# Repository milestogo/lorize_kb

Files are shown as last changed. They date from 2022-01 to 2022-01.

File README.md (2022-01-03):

# Lorize: a family of low profile 60% ergonomic keyboards that aren't too weird.  

These should be familiar to users of a MS natural or Sculpt keyboard, but pull in elements from the boardrun, alice, and kinesis keyboards. 
Available in desktop and MNT reform versions.

The lorize.scad file is intended to be used with the openscad configurator. You can change the type of keyboard (desktop, laptop, mutants), and the layer. The output can be used for laser cutting plate and case files. The POS files are used as an easy way to export centroid information from kicad & import into SCAD, which is used to make the bottom layer cutouts. 

lorize3 folder is for a desktop version of the PCB. it can be split for tenting, or used unsplit. This PCB can be soldered using only through hole 
techniques (no stencil).

The PCB for the laptop version is located at github milestogo/reform,in the ergo1 branch. This was done as a remix of the original keyboard, so that the factory firmware will still work. The board was updated to be single sided to reduce cost/effort of assembly. There isn't quite enough room to fit on top to fit a pro micro, so it requires SMD work. 

#Todos.
Vertical spacing between switches is using 17mm spacing. This feels big if you use MBK or other low height keycaps.  
For ease of hand routing, the laptop PCB has some weird parts I built. The diodes could be changed & the board autorouted. 

The desktop version's RGB LEDs aren't well placed. Consider replacing with crenelated tabs to solder LED strip on the edge. . 

The laptop version doesn't have RGB LEDs,underglow would work well for the MNT case, or edge lit by the trackpad.

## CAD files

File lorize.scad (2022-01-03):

include <part-POS.scad>;

$fn=30;

angle=14; //Total opening angle
splita=angle/2; 
colstep=19; // horizontal center to center distance between switches
rowstep=18; // ibid, vertical
m3=3.1/2;//radius of m3 hole

/* [Hole Type:] */
// Pick layer to set hole type. 0 = debug, 1 = switchplate
layer = 0; // [0:caps_debug, 1:switchplate, 2:pcb_frame, 3:pcb_shim, 4:palm_mid, 5: palm_rest] 

caps_debug=0;
switchplate=1;
pcb_frame=2;
palm_mid=4; 
palm_rest=5;

/* [ Enum of board types ] */
desktop = 0; //60% best overall ergos, custom PCB shape. 
maxreform = 1; // option with as many keys as we can cram in. 
reform = 2; // 60% that fits well enough for a reform sized PCB
smallreform_thumb =3 ;// 30% option with more thumbs for reform.  
long=1; // used to flag if switch has long or standard cap. 


/* [ Board Type:] */
board = 0; // [ 1:maxreform, 2:reform, 0:desktop, 3:smallreform_thumb]



/* [ PCB Size]*/
reform_pcbx = 275.9;
reform_pcby = 102.24;




// mcu board size
mcu_x= 34; // pro micro 33, feather 51
mcu_y= 19.5; // pro micro 19 /bluepill 22.6 / feather 23
mcu_z=8;





module rtate(x,y, a) {

	newx= x*cos(a) - y*sin(a);
	newy= x*sin(a) + y*cos(a);
}

//// Functions

/// x_origin,y_origin, angle of orgin from horizontal, x increment ,y increment, additional angle of column, separation between hands, do_longkey, per_key_rotation
module debugkey(x_o,y_o,a_o,x,y,a_col, separation,long,a_key,is_mirror) {

// even if we are mirroring motions, don't want to mirror parts. So mirror them again. 

	translate([separation,0,0]) {
		rotate(a_o)
			translate([x_o,y_o,0])
				rotate(a_col)
				translate([x,y,0])
					
						if(long) {
							if(a_key) {
								rotate(a_key) 
									if(is_mirror) {
										mirror([1,0,0])
											dolongkey();
									} else {
										dolongkey();
									}
							} else {
								if(is_mirror) {
										mirror([1,0,0])
											dolongkey();
									} else {
										dolongkey();
									}
							}
						} else {
							if(a_key) {
								rotate(a_key) 
									if(is_mirror) {
										mirror([1,0,0])
											dokey();
									} else {
										dokey();
									}
							} else {
								if(is_mirror) {
										mirror([1,0,0])
											dokey();
									} else {
										dokey();
									}
							}
						}

	}

	innerx=(x*cos(a_col) - y*sin(a_col));

	innery=(x*sin(a_col) + y*cos(a_col));

	outangle=a_key+a_col+a_o;
	out_x= separation + ( (x_o+innerx)*cos(a_o) - (y_o+innery)*sin(a_o))  ;
	out_y=  ( (x_o+innerx)*sin(a_o) + (y_o + innery) * cos(a_o))   ;

	if ( 0 == layer) { // debug caps 
		color ("blue")
			translate([out_x,out_y,0])
				rotate(outangle)
					circle(4/2);

	}
		echo ("Right at ",out_x +130 , 100-out_y, outangle) ;
		//echo ("Left at ",130-out_x , 100-out_y, outangle) ;
}	


module do_mcu_under(angle){

for (y=[-7.62,7.62]) {
	hull(){
		for(x=[-14,14])
			translate([x,y])
				circle(r=3.25/2);
		}
	}
}



module do_choc_under(){

	hull(){

		circle(r=3.7/2); // stem

		translate([-5.5,0,0]) // left peg
				circle(r=2/2);

		hull(){ // link connectors connector
			translate([-5,-3.75])
				circle(r=3.5/2);

			translate([0,-5.95])
				circle(r=3.5/2);

		}
			translate([-5,-3.75])
				square([4.8 ,5],center=true);

			translate([0,-5.95])
				square([4.4,5],center=true);

	}

		/*	pcb mount choc pin. Remove if not needed
			translate([5.5,0,0])
				circle(r=1.9/2);
		*/

		// choc mount
		translate([-8.275,-3.8]) // pad left
			square([2.8,2.8],center=true);
		translate([3.275,-5.95]) // pad right
			square([2.8,2.8],center=true);
	
}

module dokey(){
/* how big is a 1u choc cap?
generic black keycap set, x=17.6 y=16.65
PLUM keyboard 18x18
per key white 17.6x16.65
transparent 17.45 x 17.82
mbk 17,48 x 16.43
*/

	if ( 0 == layer) { // debug caps 
		difference(){
			square([17.75,17],center=true);
			circle(r=3);
		}
	} else if ( 1 == layer) { // switch plate
		square([14,14],center=true);

	} else { // PCB - replace with choc pcb footprint some day - useful for kicad conversion later?
		do_choc_under();
	}
}


module dolongkey(){
/* how big is a 1.5u?

generic nylon 26.6x16.6
generic white 26.7x16.65
generic black 26.55x16.5
mbk 26.6 x 16.5

*/
	if ( 0 == layer) {
		difference(){
			square([26.75,17],center=true);
			circle(r=3);
		}
	} else if ( 1 == layer) {
		square([14,14],center=true);

	} else { // PCB
		 do_choc_under();
	}
}



//  Punch out one half of the shape. 
module doright(	angles, vfudge,hfudge,rowlow,rowhi, separation, is_mirror ){	
			for (x=[1:5]) { // starting with middle finger towards pinky

				for(y=[rowlow[x]:rowhi[x]]) {
					debugkey (  (x-2)*colstep,0, splita,
								hfudge[x],vfudge[x]+(y)*rowstep, angles[x] ,separation, 0,0,is_mirror);
						
				}

				if (5==x) { // pinky shift key is special. 
					
					if (board == smallreform_thumb ) { // why can't the laptop have a big key too?
						debugkey ( 1+(x-2)* colstep, 0 , splita, 
								-0.5,  vfudge[x]+(-1)*rowstep , angles[x],separation,0,0,is_mirror);
					} else {
					
						debugkey ( (x-2+0.25)* colstep, 0 , splita, 
								-0.5,  vfudge[x]+(-1)*rowstep , angles[x],separation,1,0,is_mirror);
					}
				

				// pinky menu key	
						// small reform uses 1u keys, mostly for aesthetics. others use larger 1.5U
						if  (board != smallreform_thumb ) {
							debugkey ( (colstep*2.25), 0 , splita ,
								-0.75, -0.25+ vfudge[x] -2*rowstep, angles[x-1], separation, 1, 0,is_mirror);
						}
		
					// pinky ctrl key  
					if ( (board == maxreform) || board == desktop ) {				
						debugkey ( (3.5-.125)* colstep, 0 , splita, 
							2,   -1.5 - vfudge[x] -(2)*rowstep , angles[x], separation,0,0,is_mirror);
							}
				}

			
			}

			// x=0 index fingers have extra rotation to bring up spacebar y location. 
	 		for (x=0) {
				for(y=[rowlow[x]:rowhi[x]]) {
						debugkey ( (x-2)*colstep, 0 , splita ,
								hfudge[x], vfudge[x]+(y)*rowstep, angles[x], separation,0, -splita*0.55,is_mirror);
				}
			}


			// Far reach pinky keys 
			if ( (board == maxreform) || (board == reform)) {
								
				for (x=6) { // weird pinky keys

						if (board == maxreform || (board == reform) ) {
						for(y=[rowlow[x]]) {
							debugkey ( (x-2)*colstep, 0 , splita ,
								hfudge[x], vfudge[x]+(y-.5)*rowstep, angles[x], separation,0, 90,is_mirror);
						}

					}
				


				}
			}
}




module do_mcu(a){
//		[0,-4+66-mcu_y/2,0]	

// Pro micro
	color("blue")
		translate([0,-4+66-mcu_y/2,0]	) { // board+diameter
			rotate(a)
				hull()
					for(ix=[-1,1])
						for(iy=[-1,1])
							translate([ix*mcu_x/2,iy*mcu_y/2,0])
								circle(r=0.1);

				}
						


}





// desktop shape functions. 

module walkpoints(radius, start, count, nodes){
	for ( c=[start:count]) {
		translate(nodes[c])
			circle(r=radius);
	}
}


RightCorners=[ [0,0],
			[0,58],  // center top
					[62,64], //  outsidetop of mcu holder 192,36
					[72,48],// near u key // 205,49.5
					[112.5,49],// upper right
					[125,3], // bump on side
					[129,-35], //bottom right
					[27,-53], // side of spacebar
					[0,-53], // bottom center	
					[0,0],					
	];




/*raw, center at x=130,y=100
130,42
130,100
130, 153
200,49
60,49
254,98
6,98
148,135
112,135
*/

MountingHoles= [
[0,58],
[0,0],
[0,-53],
[70,51], [-70,51],
[-124,2], [124,2],
[18,-36],[-18,-35],
]
;


front=140;
gap=-20;
PalmrestMid =[  // middle ones, no gap added to allow access to keys
					[142,10-front],
					[129,-35], //bottom right
					[27,-53], // side of spacebar
					[0,-53], // bottom center
					[40,5-front],
					[00,5-front],
	];


PalmrestTop =[  // middle ones, no gap added to allow access to keys
					[142,10-front],
					[129,-35], //bottom right
					[40,-53], // side of spacebar
					[70,-53], // bottom center
					[50,5-front],
				
	];


LowerPalmrestCorners =[ 
					[145,10-front],
					[129,-35], //bottom right
					[27,-53], // side of spacebar
					[0,-53], // bottom center
					[50,-front],
					[0,-front],
			
	];


module hullpalms_mid() {  // upper palms
// no fancy angles, so we can do both sides. 
	difference() { 
			union() {
				hull()
					walkpoints(5, 0, 5, PalmrestMid);
		
				mirror([1,0,0])
					hull()
						walkpoints(5, 0, 5, PalmrestMid);
			
			}


		scale(1.01)
			hullaplate();

			// centering holes for palmrest. 
		for (x=[100,80,-80,-100]) 
			translate([x,-100,0])
				circle(r=3/2);

	}
}


	module hullpalms_top() {  // upper palms
// no fancy angles, so we can do both sides. 
	difference() { 
			union() {
				hull()
					walkpoints(5, 0, 4, PalmrestTop);
		
				*mirror([1,0,0])
					hull()
						walkpoints(5, 0, 5, PalmrestTop);
			
			}

		translate([0,-18,0])
		scale(1.05)
			hullaplate(0);


		translate([0,-150])
			rotate(45)
				square([150,150]);

			// centering holes for palmrest. 
		for (x=[100,80]) 
			translate([x,-100,0])
				circle(r=3/2);


	}
	
}
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

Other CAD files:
part-POS.scad

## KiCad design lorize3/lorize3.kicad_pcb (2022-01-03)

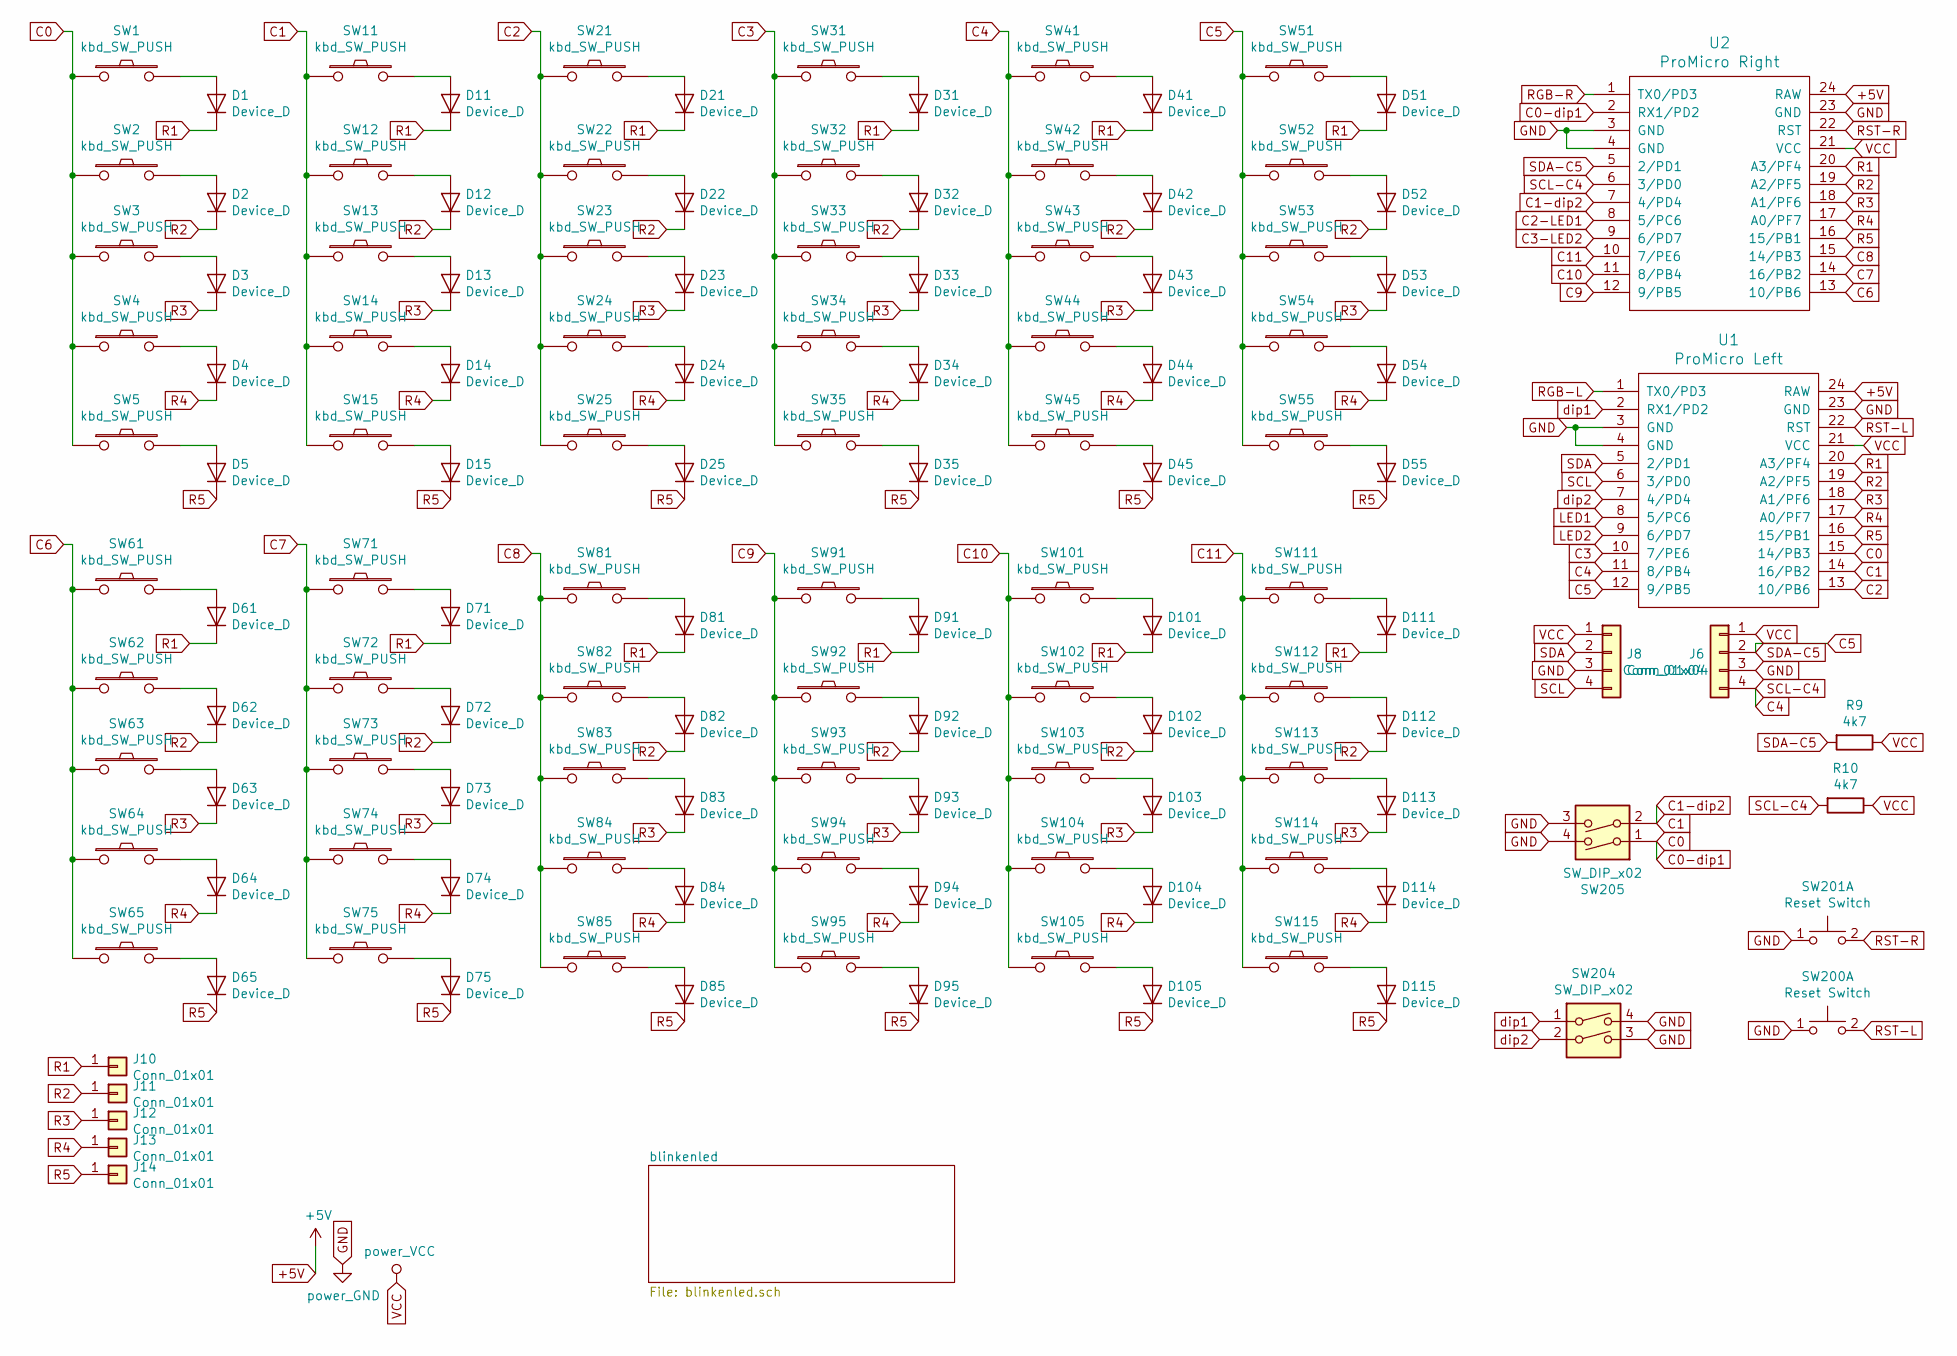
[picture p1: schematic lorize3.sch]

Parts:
D1, D2, D3, D4, D5, D11, D12, D13, D14, D15, D21, D22, D23, D24, D25, D31, D32, D33, D34, D35, D41, D42, D43, D44, D45, D51, D52, D53, D54, D55, D61, D62, D63, D64, D65, D71, D72, D73, D74, D75, D81, D82, D83, D84, D85, D91, D92, D93, D94, D95, D101, D102, D103, D104, D105, D111, D112, D113, D114, D115: Device_D; Diode-Hybrid-Back
J6, J8: Conn_01x04; 1X04_LONGPADS
J10, J11, J12, J13, J14: Conn_01x01; 1X01_LONGPAD
R9, R10: 4k7; Resistor-Hybrid-Back
SW1, SW2, SW3, SW4, SW5, SW11, SW12, SW13, SW14, SW15, SW21, SW22, SW23, SW24, SW25, SW31, SW32, SW33, SW34, SW35, SW41, SW42, SW43, SW44, SW45, SW51, SW52, SW53, SW54, SW55, SW61, SW62, SW63, SW64, SW65, SW71, SW72, SW73, SW74, SW75, SW81, SW82, SW83, SW84, SW85, SW91, SW92, SW93, SW94, SW95, SW101, SW102, SW103, SW104, SW105, SW111, SW112, SW113, SW114, SW115: kbd_SW_PUSH; Kailh_socket_PG1350
SW200, SW201: Reset Switch; SW_Tactile_SPST_Angled_MJTP1117
SW204, SW205: SW_DIP_x02; SW_DIP_SPSTx02_Slide_6.7x6.64mm_W7.62mm_P2.54mm_LowProfile
U1: ProMicro Left; ArduinoProMicro-notopsilk
U2: ProMicro Right; ArduinoProMicro-notopsilk

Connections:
+5V: U1.24 (RAW), U2.24 (RAW); also elsewhere on the board
C0: SW1.1, SW2.1, SW3.1, SW4.1, SW5.1, SW205.1, U1.15 (14/PB3), U2.2 (RX1/PD2)
C1: SW11.1, SW12.1, SW13.1, SW14.1, SW15.1, SW205.2, U1.14 (16/PB2), U2.7 (4/PD4)
C2: SW21.1, SW22.1, SW23.1, SW24.1, SW25.1, U1.13 (10/PB6), U2.8 (5/PC6); also elsewhere on the board
C3: SW31.1, SW32.1, SW33.1, SW34.1, SW35.1, U1.10 (7/PE6), U2.9 (6/PD7); also elsewhere on the board
C4: J6.4, R10.2, SW41.1, SW42.1, SW43.1, SW44.1, SW45.1, U1.11 (8/PB4), U2.6 (3/PD0)
C5: J6.2, R9.2, SW51.1, SW52.1, SW53.1, SW54.1, SW55.1, U1.12 (9/PB5), U2.5 (2/PD1)
C6: SW61.1, SW62.1, SW63.1, SW64.1, SW65.1, U2.13 (10/PB6)
C7: SW71.1, SW72.1, SW73.1, SW74.1, SW75.1, U2.14 (16/PB2)
C8: SW81.1, SW82.1, SW83.1, SW84.1, SW85.1, U2.15 (14/PB3)
C9: SW91.1, SW92.1, SW93.1, SW94.1, SW95.1, U2.12 (9/PB5)
C10: SW101.1, SW102.1, SW103.1, SW104.1, SW105.1, U2.11 (8/PB4)
C11: SW111.1, SW112.1, SW113.1, SW114.1, SW115.1, U2.10 (7/PE6)
GND: J6.3, J8.3, SW200.1, SW201.1, SW204.3, SW204.4, SW205.3, SW205.4, U1.3 (GND), U1.4 (GND), U1.23 (GND), U2.3 (GND), U2.4 (GND), U2.23 (GND); also elsewhere on the board
LED1: U1.8 (5/PC6); also elsewhere on the board
LED2: U1.9 (6/PD7); also elsewhere on the board
unnamed: D1.2 (A), SW1.2
unnamed: D2.2 (A), SW2.2
unnamed: D3.2 (A), SW3.2
unnamed: D4.2 (A), SW4.2
unnamed: D5.2 (A), SW5.2
unnamed: D11.2 (A), SW11.2
unnamed: D12.2 (A), SW12.2
unnamed: D13.2 (A), SW13.2
unnamed: D14.2 (A), SW14.2
unnamed: D15.2 (A), SW15.2
unnamed: D21.2 (A), SW21.2
unnamed: D22.2 (A), SW22.2
unnamed: D23.2 (A), SW23.2
unnamed: D24.2 (A), SW24.2
unnamed: D25.2 (A), SW25.2
unnamed: D31.2 (A), SW31.2
unnamed: D32.2 (A), SW32.2
unnamed: D33.2 (A), SW33.2
unnamed: D34.2 (A), SW34.2
unnamed: D35.2 (A), SW35.2
unnamed: D41.2 (A), SW41.2
unnamed: D42.2 (A), SW42.2
unnamed: D43.2 (A), SW43.2
unnamed: D44.2 (A), SW44.2
unnamed: D45.2 (A), SW45.2
unnamed: D51.2 (A), SW51.2
unnamed: D52.2 (A), SW52.2
unnamed: D53.2 (A), SW53.2
unnamed: D54.2 (A), SW54.2
unnamed: D55.2 (A), SW55.2
unnamed: D61.2 (A), SW61.2
unnamed: D62.2 (A), SW62.2
unnamed: D63.2 (A), SW63.2
unnamed: D64.2 (A), SW64.2
unnamed: D65.2 (A), SW65.2
unnamed: D71.2 (A), SW71.2
unnamed: D72.2 (A), SW72.2
unnamed: D73.2 (A), SW73.2
unnamed: D74.2 (A), SW74.2
unnamed: D75.2 (A), SW75.2
unnamed: D81.2 (A), SW81.2
unnamed: D82.2 (A), SW82.2
unnamed: D83.2 (A), SW83.2
unnamed: D84.2 (A), SW84.2
unnamed: D85.2 (A), SW85.2
unnamed: D91.2 (A), SW91.2
unnamed: D92.2 (A), SW92.2
unnamed: D93.2 (A), SW93.2
unnamed: D94.2 (A), SW94.2
unnamed: D95.2 (A), SW95.2
unnamed: D101.2 (A), SW101.2
unnamed: D102.2 (A), SW102.2
unnamed: D103.2 (A), SW103.2
unnamed: D104.2 (A), SW104.2
unnamed: D105.2 (A), SW105.2
unnamed: D111.2 (A), SW111.2
unnamed: D112.2 (A), SW112.2
unnamed: D113.2 (A), SW113.2
unnamed: D114.2 (A), SW114.2
unnamed: D115.2 (A), SW115.2
R1: D1.1 (K), D11.1 (K), D21.1 (K), D31.1 (K), D41.1 (K), D51.1 (K), D61.1 (K), D71.1 (K), D81.1 (K), D91.1 (K), D101.1 (K), D111.1 (K), J10.1, U1.20 (A3/PF4), U2.20 (A3/PF4); also elsewhere on the board
R5: D5.1 (K), D15.1 (K), D25.1 (K), D35.1 (K), D45.1 (K), D55.1 (K), D65.1 (K), D75.1 (K), D85.1 (K), D95.1 (K), D105.1 (K), D115.1 (K), J14.1, U1.16 (15/PB1), U2.16 (15/PB1); also elsewhere on the board
RGB-L: U1.1 (TX0/PD3); also elsewhere on the board
RGB-R: U2.1 (TX0/PD3); also elsewhere on the board
RST-L: SW200.2, U1.22 (RST)
RST-R: SW201.2, U2.22 (RST)
SCL: J8.4, U1.6 (3/PD0)
SDA: J8.2, U1.5 (2/PD1)
VCC: J6.1, J8.1, R9.1, R10.1, U1.21 (VCC), U2.21 (VCC); also elsewhere on the board
dip1: SW204.1, U1.2 (RX1/PD2)
dip2: SW204.2, U1.7 (4/PD4)

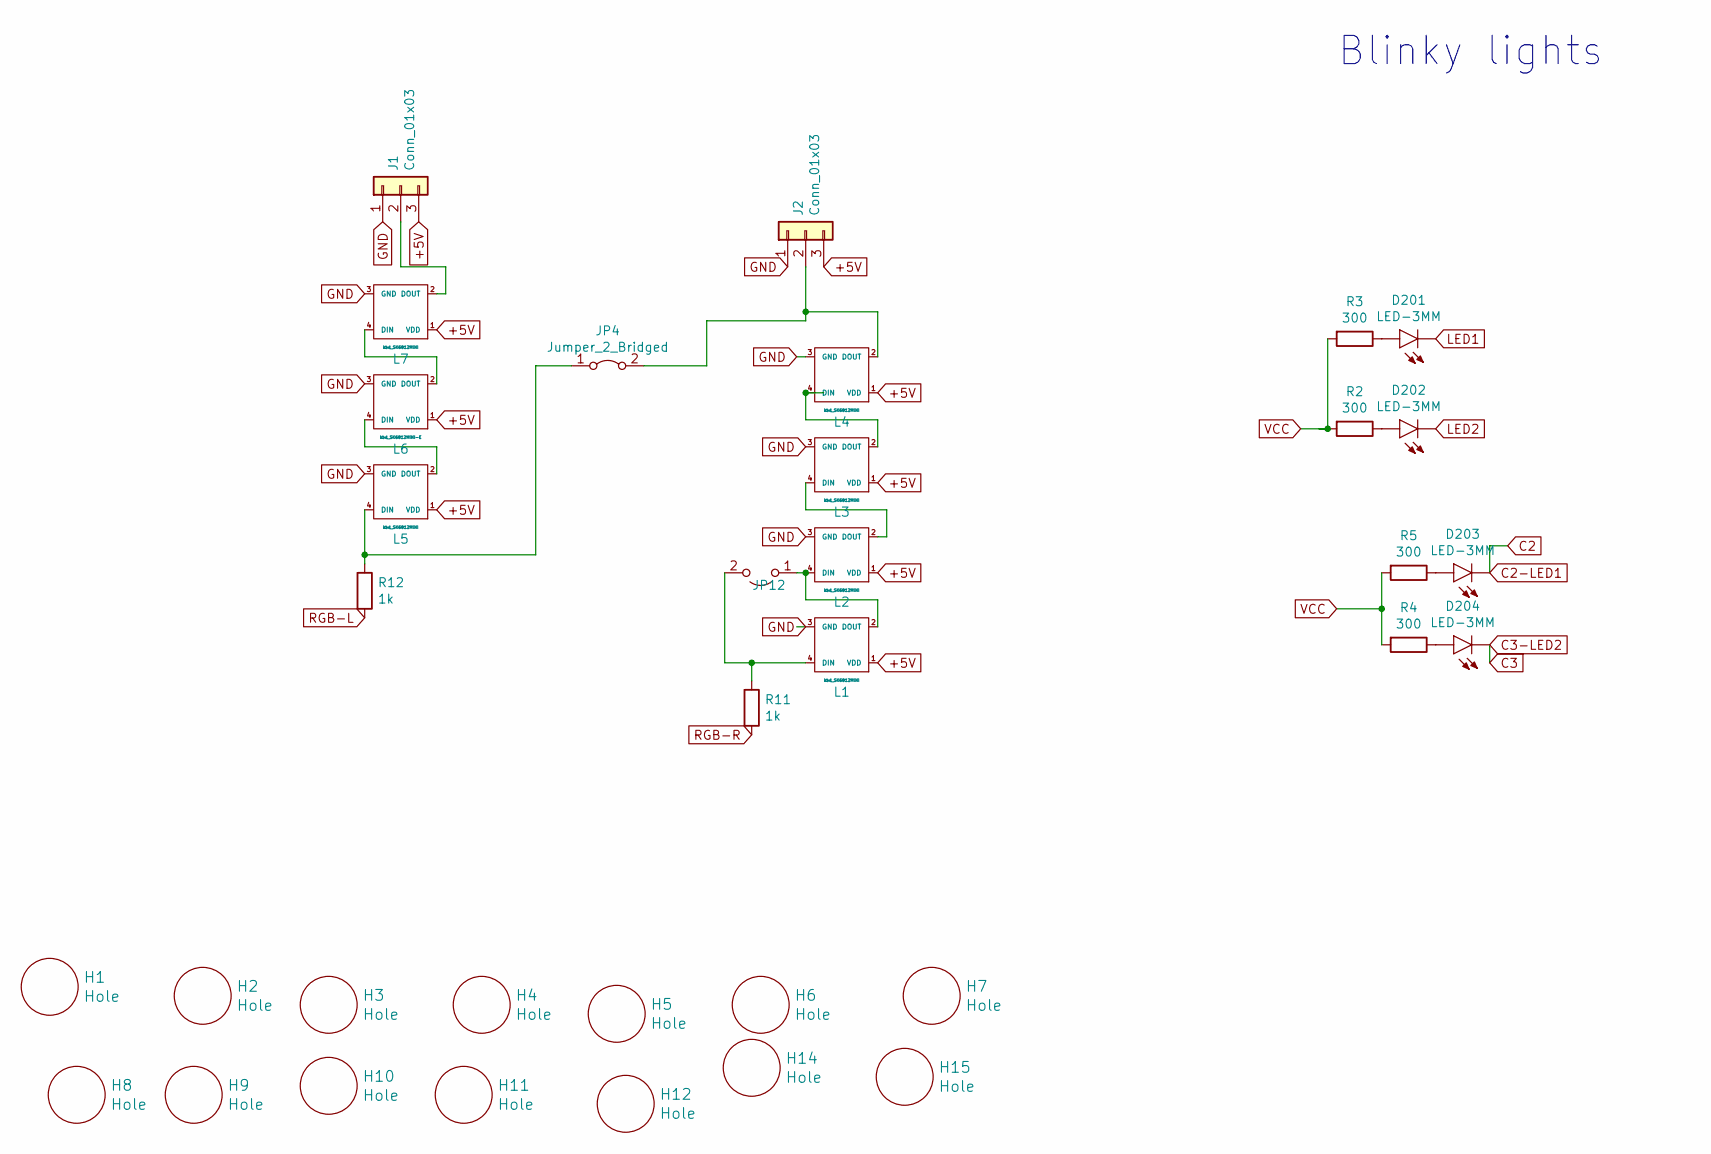
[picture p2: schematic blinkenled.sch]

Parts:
D201, D202, D203, D204: LED-3MM; LED_3mm_Radial
H1, H11, H12, H14, H15: Hole; breakaway-mousebites
H2, H3, H4, H5, H6, H7, H8, H9, H10: Hole; MountingHole_3.2mm_M3
J1, J2: Conn_01x03; 1X03_LONGPADS
JP4: Jumper_2_Bridged; ThickJumper
JP12: Jumper_2_Open; JUMPER_SMD_2DUB
L1, L2, L3, L4, L5, L7: kbd_SK6812MINI; SK6812-MINI-E
L6: kbd_SK6812MINI-E; SK6812-MINI-E
R2, R3, R4, R5: 300; Resistor-Hybrid-Back
R11, R12: 1k; Resistor-Hybrid-Back

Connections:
+5V: J1.3, J2.3, L1.1 (VDD), L2.1 (VDD), L3.1 (VDD), L4.1 (VDD), L5.1 (VDD), L6.1 (VDD), L7.1 (VDD); also elsewhere on the board
C2: D203.K (C); also elsewhere on the board
C3: D204.K (C); also elsewhere on the board
GND: J1.1, J2.1, L1.3 (GND), L2.3 (GND), L3.3 (GND), L4.3 (GND), L5.3 (GND), L6.3 (GND), L7.3 (GND); also elsewhere on the board
LED1: D201.K (C); also elsewhere on the board
LED2: D202.K (C); also elsewhere on the board
unnamed: D203.A, R5.1
unnamed: J1.2, L7.2 (DOUT)
unnamed: J2.2, JP4.2 (B), L4.2 (DOUT)
unnamed: JP4.1 (A), L5.4 (DIN), R12.1
unnamed: JP12.1 (A), L1.2 (DOUT), L2.4 (DIN)
unnamed: JP12.2 (B), L1.4 (DIN), R11.1
unnamed: L2.2 (DOUT), L3.4 (DIN)
unnamed: L3.2 (DOUT), L4.4 (DIN)
unnamed: L5.2 (DOUT), L6.4 (DIN)
unnamed: L6.2 (DOUT), L7.4 (DIN)
RGB-L: R12.2; also elsewhere on the board
RGB-R: R11.2; also elsewhere on the board
VCC: R2.2, R3.2, R4.2, R5.2; also elsewhere on the board

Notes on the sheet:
Blinky lights

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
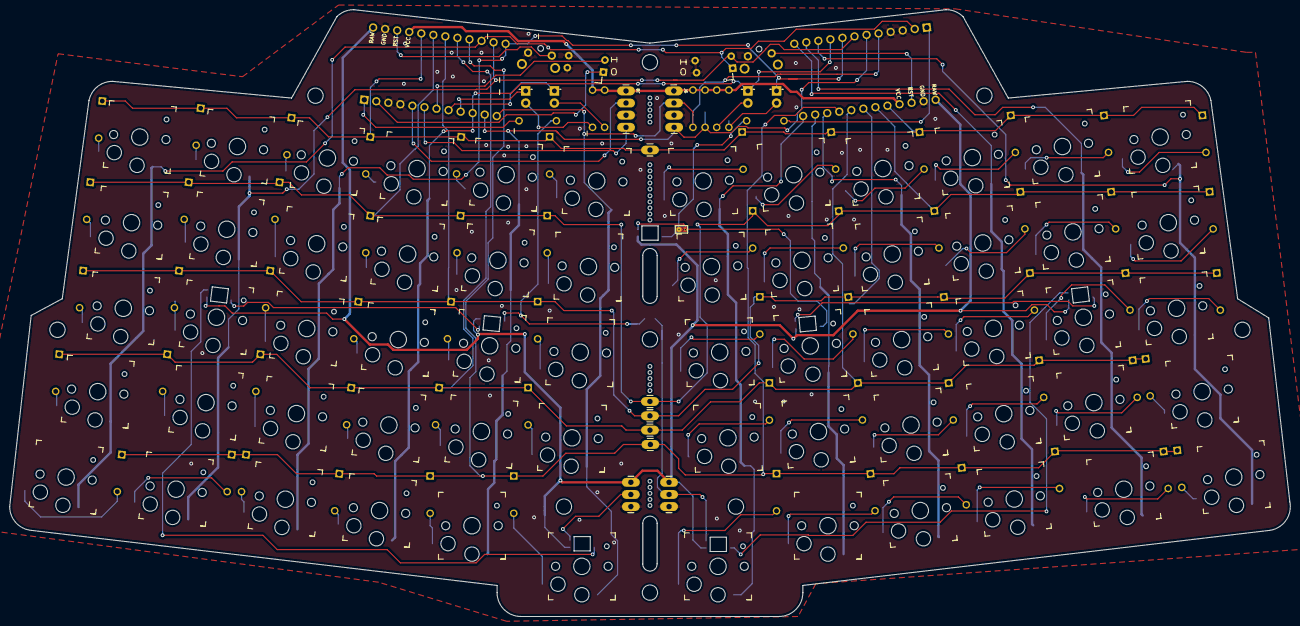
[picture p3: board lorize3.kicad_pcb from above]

Board: 2 copper layers, 268.0 x 127.0 mm, 170 parts (1 on the bottom side), 103 nets.

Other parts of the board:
R1, R5#2: Conn_01x01; 1X01_LONGPAD
R2#2, R3#2, R4#2: 300; Resistor-Hybrid-Back

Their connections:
R1: R1.1; also elsewhere on the board
R5: R5#2.1; also elsewhere on the board
VCC: R2#2.2, R3#2.2, R4#2.2; also elsewhere on the board
